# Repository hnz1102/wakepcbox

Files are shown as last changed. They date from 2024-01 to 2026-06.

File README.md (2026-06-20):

<div align="center">
  <h1><code>Wake PC Box</code></h1>
  <p>
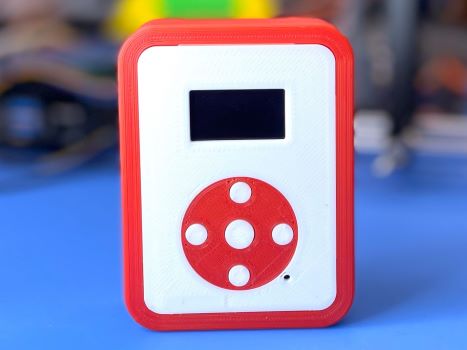
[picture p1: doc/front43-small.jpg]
    
  </p>
</div>

# Wake PC Box - Wake On LAN Packet Transmitting Box

Video
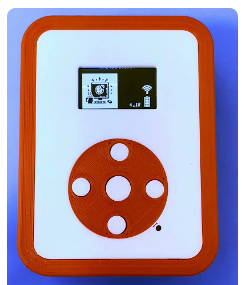
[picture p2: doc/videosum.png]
demo video (https://www.youtube.com/watch?v=YX_4e1eiLbk)


This is the small control box that can wake up the PC using Wake On LAN. You can just push a button, PCs will wake up from the power off status.
There is no need to start up another PC in order to start up a PC with Wake On Lan. Wake on LAN packets are sent via WiFi LAN.
The Box has a battery, and you can charge it from a USB Type-C port. Once charging full, you can use it for a month. If any buttons are not pressed for the specified time (default 30 seconds), the box will sleep automatically and conserve battery power. Up to four PCs can be registered.

# Update History
- 2024-05-30 : Initial Release
- 2026-02-14 : Update code for ESP-IDF V5.4.2 and update README.md
- 2026-06-20 : v0.2.0 - Add WPS PBC mode support, fix WPS display overlap, fix WiFi menu not reflecting WPS credentials immediately

# How it works

This box can send a Wake on LAN packet to the Wireless Access Point. To transfer the packet, the Access Point needs to be set to `Bridge Mode`. If `Router Mode` is set, the Access Point won't transfer to the wired LAN. 

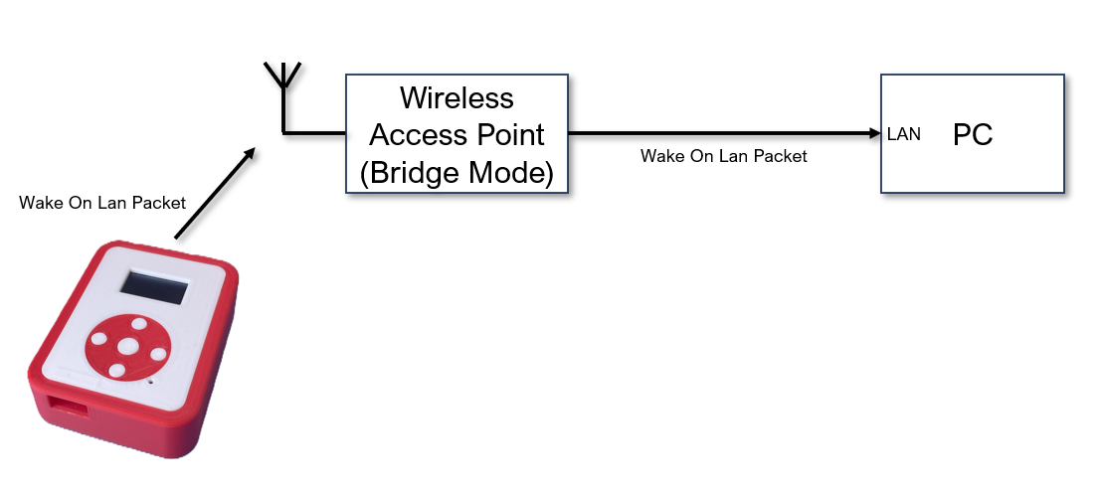
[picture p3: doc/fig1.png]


# Feature

**Quick Wake Up** -  Simply press one of the up, down, left, or right buttons to turn on the PC corresponding to that button. 4 PCs can be registered.

**Microcontroller on board** - No need for a PC when you turn on another PC. Directly send packets to the target PCs. 

**Transmit a packet via WiFi** - Wake-on LAN packets are transmitted via Wireless Network.

**Battery Powered** - Using LiPo battery. It can run for a month (In this case, every day a few times used).

**Small Handy Box** - This box is only 60mm(W) x 23mm(H) x 80mm(D) size. No need for any cables, it works. 

**Configurable** - Setting parameters are set from the display menu. SSID/Password/Target PC Hardware Address(4 PCs)/Time Zone/Sleep Time/Sleep Mode/Display Off Time/Reset Settings.

**WPS Support** - If `wps_enable = "true"` and `wifi_ssid` is empty in `cfg.toml`, the device enters WPS PBC (Push Button Configuration) mode on first boot. Press the WPS button on your router within 120 seconds. The obtained SSID and password are saved to NVS automatically, and subsequent boots connect normally without WPS.

# How to Use the Box
At first, you can set the WiFi SSID and PSK-Password in one of two ways:

**Option A: Manual entry via menu** - Push the Center Key to open the setting menu, select `WiFi`, then enter your SSID and password using the direction keys.

**Option B: WPS PBC mode** - Set `wps_enable = "true"` and leave `wifi_ssid` empty in `cfg.toml` before flashing. On first boot, the device displays "WPS MODE" and waits up to 120 seconds. Press the WPS button on your router to transfer the credentials automatically. The SSID and password are saved and WPS mode is disabled for subsequent boots.
Next, set the Hardware Address(Ethernet MAC Address) of the PC that you want to wake up. Select `HW Address` and push Center Key, select from `PC1` to `PC4`, push Center key, then enter your Hardware Address like `00:11:22:33:44:55`. 

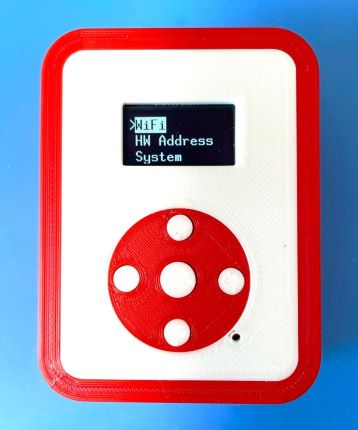
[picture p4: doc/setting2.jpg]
setting
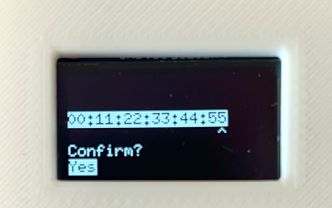
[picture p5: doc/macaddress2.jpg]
   

After setting, just push button corresponding the target.(Up Key : PC1, Down Key : PC2, Left Key: PC3, Right Key: PC4)

To charge a battery, just connect to a USB Type-C port from the bus-powered USB port. During the charge, the CHG LED is RED ON. After the charging is full, the FUL LED is GREEN ON. And the charging will be stopped automatically.

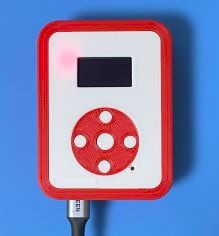
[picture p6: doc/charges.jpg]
charge
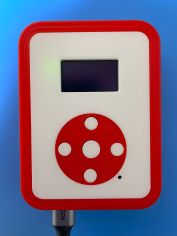
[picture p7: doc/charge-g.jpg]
charge
  

Assembled PCB

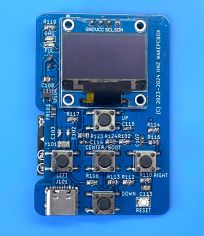
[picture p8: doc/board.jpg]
board
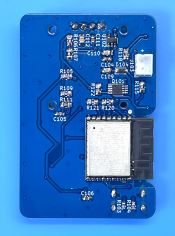
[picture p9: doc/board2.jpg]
board
    

Set in Box

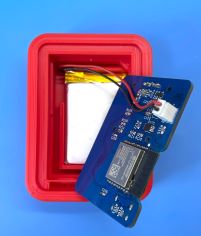
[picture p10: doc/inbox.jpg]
InBox
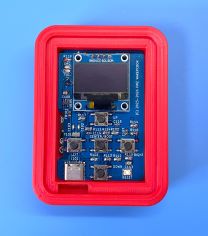
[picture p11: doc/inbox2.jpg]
InBox
   

# How to build from code and Install to the unit.

Using Ubuntu 22.04.3 LTS and ESP-IDF V5.4.2

1. Install Rust Compiler
```bash
sudo apt update && sudo apt -y install git python3 python3-pip gcc build-essential curl pkg-config libudev-dev libtinfo5 clang libclang-dev llvm-dev udev libssl-dev python3.10-venv
curl --proto '=https' --tlsv1.2 -sSf https://sh.rustup.rs | sh
```
You can see the install menu, select No.1. After installation, set the environment variable.

```bash
. "$HOME/.cargo/env"
```

2. Install toolchain for ESP32-C3
```bash
cargo install ldproxy
cargo install espup
cargo install cargo-espflash
```

3. Install ESP-IDF and set the environment variable.
```bash
espup install
espup update
```

Then, run the following command to set the environment for the ESP32-C3 toolchain:
```bash
. ./export-esp.sh
```

4. Add UDEV rules
```bash
sudo sh -c 'echo "SUBSYSTEMS==\"usb\", ATTRS{idVendor}==\"303a\", ATTRS{idProduct}==\"1001\", MODE=\"0666\"" > /etc/udev/rules.d/99-esp32.rules'
sudo udevadm control --reload-rules
sudo udevadm trigger
```

5. Download Current-Logger code
```bash
git clone https://github.com/hnz1102/wakepcbox.git
cd wakepcbox
``` 
6. Setting WiFi SSID, Password, and InfluxDB server IP address.
```bash
cfg.toml

[wakepcbox]
wifi_ssid = "<SSID>"      # Set your AP SSID. Leave empty to use WPS mode.
wifi_psk = "<Password>"   # Set password for SSID.
wps_enable = "false"       # Set "true" to use WPS PBC mode on first boot (requires wifi_ssid to be empty).
target_mac_address1 = "00:00:00:00:00:00"  # Set Hardware Address(MAC Address) for wakeup.
target_mac_address2 = "00:00:00:00:00:00"
target_mac_address3 = "00:00:00:00:00:00"
target_mac_address4 = "00:00:00:00:00:00"
timezone_offset = "0"
idle_in_sleep_time = "30"
sleep_mode = "light"
display_off_time = "30"
wakeup_interval = "10"
```
7. Build code and writing flash
```bashbash
cargo build --release
```

8. Connecting the board and Set device and set toolchain.

Connecting the Box by USB Type-C to this code building PC. Then, 

```bash
cargo espflash board-info

✔ Use serial port '/dev/ttyACM0' - USB JTAG/serial debug unit? · yes
✔ Remember this serial port for future use? · yes
[2026-02-14T04:41:35Z INFO ] Serial port: '/dev/ttyACM0'
[2026-02-14T04:41:35Z INFO ] Connecting...
[2026-02-14T04:41:36Z INFO ] Using flash stub
Chip type:         esp32c3 (revision v0.4)
Crystal frequency: 40 MHz
Flash size:        4MB
Features:          WiFi, BLE
MAC address:       a0:76:4e:b3:64:c0

Security Information:
=====================
Flags: 0x00000000 (0)
Key Purposes: [0, 0, 0, 0, 0, 0, 12]
Chip ID: 5
API Version: 3
Secure Boot: Disabled
Flash Encryption: Disabled
SPI Boot Crypt Count (SPI_BOOT_CRYPT_CNT): 0x0
```

9. Writing flash
```bash
cargo espflash flash --release --monitor

[2026-02-14T04:43:53Z INFO ] Serial port: '/dev/ttyACM0'
[2026-02-14T04:43:53Z INFO ] Connecting...
[2026-02-14T04:43:53Z INFO ] Using flash stub
   Compiling wakepcbox v0.1.0 (/wakepcbox)
    Finished `release` profile [optimized] target(s) in 4.22s
Chip type:         esp32c3 (revision v0.4)
Crystal frequency: 40 MHz
Flash size:        4MB
Features:          WiFi, BLE
MAC address:       a0:76:4e:b3:64:c0
App/part. size:    1,644,080/3,145,728 bytes, 52.26%
[00:00:00] [========================================]      13/13      0x0      Verifying... OK!                                                                                                                                                       [00:00:00] [========================================]       1/1       0x8000   Skipped! (checksum matches)                                                                                                                                            
[00:00:15] [========================================]     887/887     0x10000  Verifying... OK!                                                                                                                                                       [2026-02-14T04:44:16Z INFO ] Flashing has completed!

And automatically boot!
```
## Schematic, PCB Gabar and Container 3D Data

There is a Schematic data in the hardware directory including 3D printing data. 

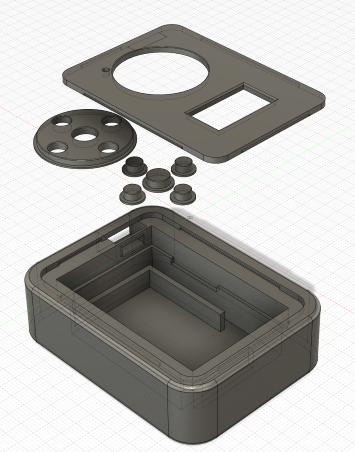
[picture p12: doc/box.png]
Container
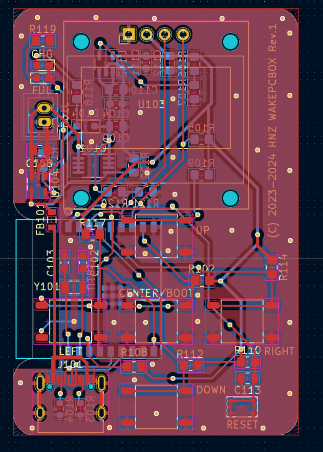
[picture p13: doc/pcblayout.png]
PCB Layout
 

## LICENSE
This source code is licensed under MIT. Other Hardware Schematic documents are licensed under CC-BY-SA V4.0.

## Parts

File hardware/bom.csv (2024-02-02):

Reference | Value | Footprint | Datasheet | digikey | distributor | Qty
C102, C103 | 16pF | Capacitor_SMD:C_0603_1608Metric_Pad1.08x0.95mm_HandSolder | ~ |  | https://www.digikey.com/en/products/detail/walsin-technology-corporation/0603N160J500CT/9354987 | 2
C104, C111 | 0.1uF | Capacitor_SMD:C_0603_1608Metric_Pad1.08x0.95mm_HandSolder | ~ |  | https://www.digikey.com/en/products/detail/yageo/CC0603ZRY5V9BB104/2103081 | 2
C108 | 4.7uF | Capacitor_SMD:C_0805_2012Metric_Pad1.18x1.45mm_HandSolder | ~ |  | https://www.digikey.com/en/products/detail/yageo/CC0805ZRY5V6BB475/2103109 | 1
C109, C113 | 1uF | Capacitor_SMD:C_0805_2012Metric | ~ |  | https://www.digikey.com/en/products/detail/yageo/CC0805ZRY5V7BB105/2833622 | 2
C110, C112 | 10uF | Capacitor_SMD:C_0805_2012Metric_Pad1.18x1.45mm_HandSolder | ~ |  | https://www.digikey.com/en/products/detail/murata-electronics/GRM21BR61C106KE15K/2546903 | 2
D102 | LED RED | LED_SMD:LED_0603_1608Metric_Pad1.05x0.95mm_HandSolder | ~ |  | https://www.digikey.com/en/products/detail/harvatek-corporation/B1931URO-20D000114U1930/15910603 | 1
D103 | LED GREEN | LED_SMD:LED_0603_1608Metric_Pad1.05x0.95mm_HandSolder | ~ |  | https://www.digikey.com/en/products/detail/harvatek-corporation/B1931NG-20D001114U1930/15861262 | 1
D104 | NSR0340HT1G | Diode_SMD:D_SOD-323_HandSoldering | https://www.onsemi.com/pub/Collateral/NSR0340H-D.PDF |  | https://www.digikey.com/en/products/detail/onsemi/NSR0340HT1G/1981491 | 1
FB101 | MH2029-601Y | Inductor_SMD:L_0805_2012Metric | ~ |  | https://www.digikey.com/en/products/detail/bourns-inc/MH2029-601Y/3741762 | 1
J101 | USB4105-GF-A | Library:USB_C_5077CR-16-SMC2-BK-TR | https://www.usb.org/sites/default/files/documents/usb_type-c.zip |  | https://www.digikey.com/en/products/detail/gct/USB4105-GF-A/11198441 | 1
J103 | LiPo BATTERY | Connector_JST:JST_PH_B2B-PH-K_1x02_P2.00mm_Vertical | ~ |  | https://www.digikey.com/en/products/detail/jst-sales-america-inc/B2B-PH-K-S/926611 | 1
Q101 | IRF7606TRPBF | Package_SO:MSOP-8_3x3mm_P0.65mm | http://www.irf.com/product-info/datasheets/data/irf7606pbf.pdf |  | https://www.digikey.com/en/products/detail/infineon-technologies/IRF7606TRPBF/856652 | 1
R102, R109, R110, R112, R114, R117 | 10K | Resistor_SMD:R_0805_2012Metric_Pad1.20x1.40mm_HandSolder | ~ |  | https://www.digikey.jp/en/products/detail/yageo/RC0603JR-1010KL/13694233 | 6
R103, R104 | 5.1K | Resistor_SMD:R_0603_1608Metric | ~ |  | https://www.digikey.com/en/products/detail/yageo/RC0603JR-075K1L/726796 | 2
R105, R108 | 10K | Resistor_SMD:R_0603_1608Metric | ~ |  | https://www.digikey.jp/en/products/detail/yageo/RC0603JR-1010KL/13694233 | 2
R106, R120, R121 | 20K 1% | Resistor_SMD:R_0805_2012Metric_Pad1.20x1.40mm_HandSolder | ~ |  | https://www.digikey.jp/en/products/detail/yageo/RC0603FR-0720KL/727040 | 3
R107 | 12K 1% | Resistor_SMD:R_0805_2012Metric_Pad1.20x1.40mm_HandSolder | ~ |  | https://www.digikey.com/en/products/detail/yageo/RC0603FR-0712KL/726913 | 1
R115 | 2K | Resistor_SMD:R_0805_2012Metric_Pad1.20x1.40mm_HandSolder | ~ |  | https://www.digikey.com/en/products/detail/yageo/RC0603JR-072KL/726726 | 1
R118, R119 | 330 | Resistor_SMD:R_0805_2012Metric_Pad1.20x1.40mm_HandSolder | ~ |  | https://www.digikey.com/en/products/detail/yageo/RC0603JR-13330RL/14286483 | 2
R122 | 100K | Resistor_SMD:R_0805_2012Metric_Pad1.20x1.40mm_HandSolder | ~ |  | https://www.digikey.com/en/products/detail/yageo/RC0603JR-07100KL/726698 | 1
SW101, SW103-SW106 | TS-06104 | Library:TS-06104 |  |  | https://akizukidenshi.com/catalog/g/g115969/ | 5
SW102 | 3.5x2.6 Tact SW | Library:WS-TASV SMT Tact Switch |  |  | https://www.digikey.com/en/products/detail/w%C3%BCrth-elektronik/435151014824/11627325 | 1
U101 | ESP32-C3-WROOM-02-N4 | Library:IC18_ESP32-C3-WROOM-02-N4_EXP | ESP32-C3-WROOM-02-N4 |  | https://www.digikey.com/en/products/detail/espressif-systems/ESP32-C3-WROOM-02-N4/14553031 | 1
U102 | SPX3819M5-L | Package_TO_SOT_SMD:SOT-23-5 | https://www.exar.com/content/document.ashx?id=22106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 |  | https://www.digikey.com/en/products/detail/maxlinear-inc/SPX3819M5-L-TR/2472388 | 1
U103 | SSD1306_DISPLAY | Library:OLED I2C DISPLAY |  |  | https://www.amazon.com/IZOKEE-Display-SSD1306-Raspberry-White-IIC/dp/B076PDVFQD/ref=sr_1_3 | 1
U104 | MCP73831-2-OT | Package_TO_SOT_SMD:SOT-23-5 | http://ww1.microchip.com/downloads/en/DeviceDoc/20001984g.pdf |  | https://www.digikey.com/en/products/detail/microchip-technology/MCP73831T-2ACI-OT/964301 | 1
Y101 | 32.7680KHz | Crystal:Crystal_SMD_3215-2Pin_3.2x1.5mm | ~ | 2151-RT3215-32.768-12.5-TRCT-ND | https://www.digikey.com/en/products/detail/raltron-electronics/RT3215-32-768-12-5-TR/10273025 | 1
BAT | LiPo Battery |  |  | https://www.amazon.com/EEMB-1100mAh-Battery-Rechargeable-Connector/dp/B08FD39Y5R | 1

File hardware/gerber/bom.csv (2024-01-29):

Designator | Footprint | Quantity | Value | LCSC Part #
C102, C103 | 0603 | 2 | 16pF
C104, C111 | 0603 | 2 | 0.1uF
C108 | 0805 | 1 | 4.7uF
C109, C113 | 0805 | 2 | 1uF
C110, C112 | 0805 | 2 | 10uF
D102 | 0603 | 1 | LED RED
D103 | 0603 | 1 | LED GREEN
D104 | D_SOD-323_HandSoldering | 1 | NSR0340HT1G
FB101 | 0805 | 1 | MH2029-601Y
J101 | USB_C_5077CR-16-SMC2-BK-TR | 1 | USB4105-GF-A
J103 | JST_PH_B2B-PH-K_1x02_P2.00mm_Vertical | 1 | LiPo BATTERY
Q101 | MSOP-8_3x3mm_P0.65mm | 1 | IRF7606TRPBF
R102, R109, R110, R112, R114, R117 | 0805 | 6 | 10K
R103, R104 | 0603 | 2 | 5.1K
R105, R108 | 0603 | 2 | 10K
R106, R120, R121 | 0805 | 3 | 20K 1%
R107 | 0805 | 1 | 12K 1%
R115 | 0805 | 1 | 2K
R118, R119 | 0805 | 2 | 330
R122 | 0805 | 1 | 100K
SW101, SW103, SW104, SW105, SW106 | TS-06104 | 5 | TS-06104
SW102 | WS-TASV SMT Tact Switch | 1 | 3.5x2.6 Tact SW
U101 | IC18_ESP32-C3-WROOM-02-N4_EXP | 1 | ESP32-C3-WROOM-02-N4
U102 | SOT-23-5 | 1 | SPX3819M5-L
U103 | OLED I2C DISPLAY | 1 | SSD1306_DISPLAY
U104 | SOT-23-5 | 1 | MCP73831-2-OT
Y101 | Crystal_SMD_3215-2Pin_3.2x1.5mm | 1 | 32.7680KHz

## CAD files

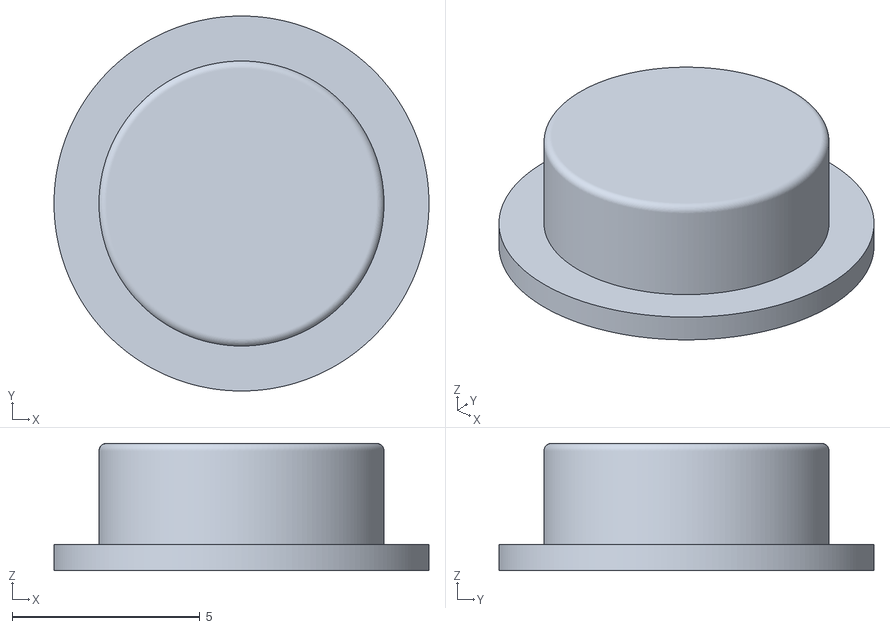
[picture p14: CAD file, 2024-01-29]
hardware/STL/button-center-v8.stl
10.0 x 10.0 x 3.40

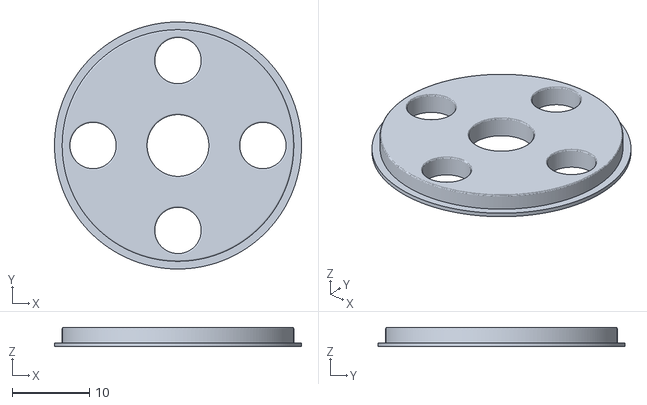
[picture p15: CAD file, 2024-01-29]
hardware/STL/button-gard-v11.stl
32.0 x 32.0 x 2.50

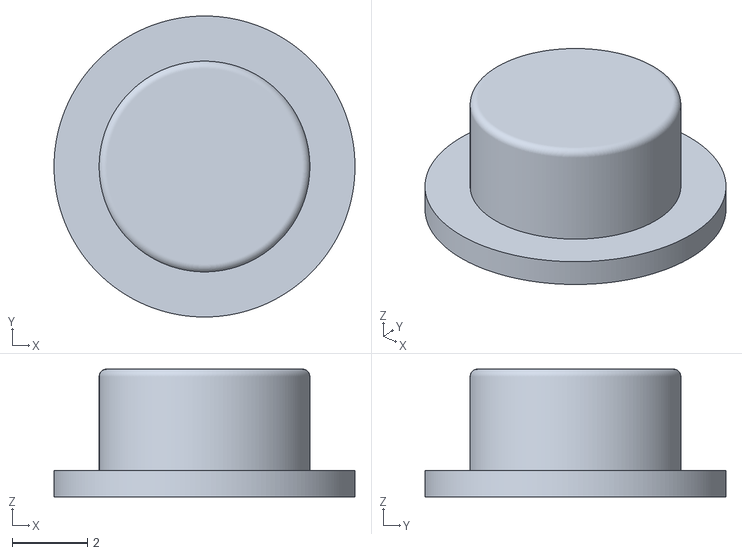
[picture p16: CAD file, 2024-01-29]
hardware/STL/button3-v8.stl
8.00 x 8.00 x 3.40

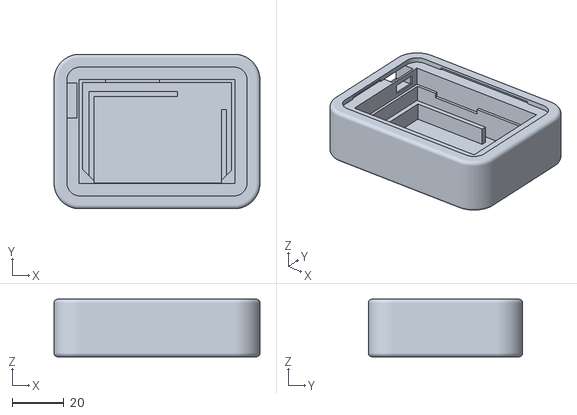
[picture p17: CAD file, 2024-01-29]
hardware/STL/bottom-v8.stl
80.0 x 60.0 x 22.4

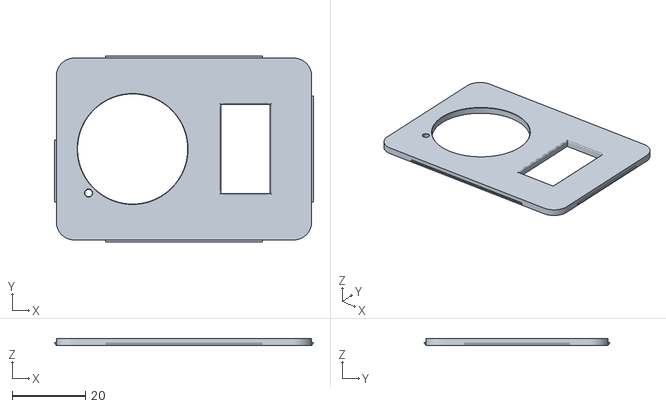
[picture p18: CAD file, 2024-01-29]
hardware/STL/upper-v8.stl
70.6 x 50.6 x 2.00

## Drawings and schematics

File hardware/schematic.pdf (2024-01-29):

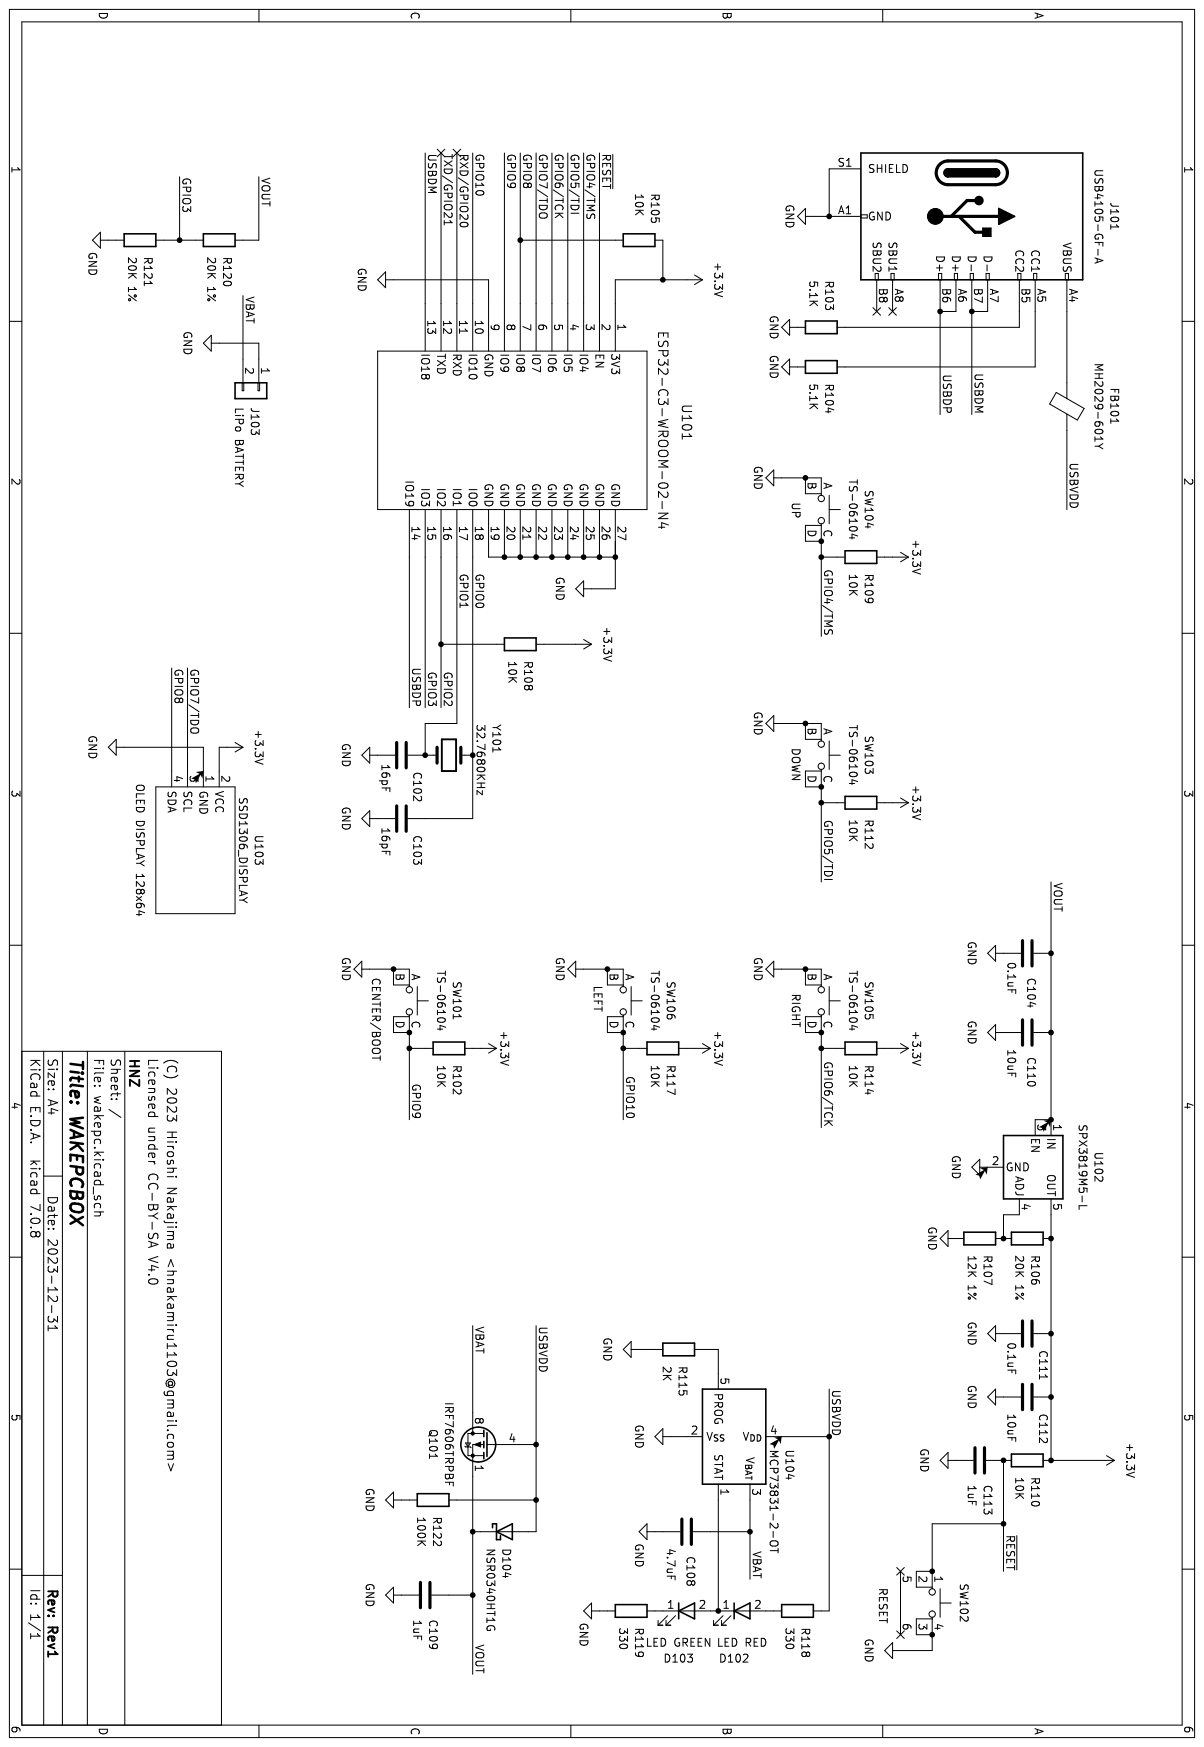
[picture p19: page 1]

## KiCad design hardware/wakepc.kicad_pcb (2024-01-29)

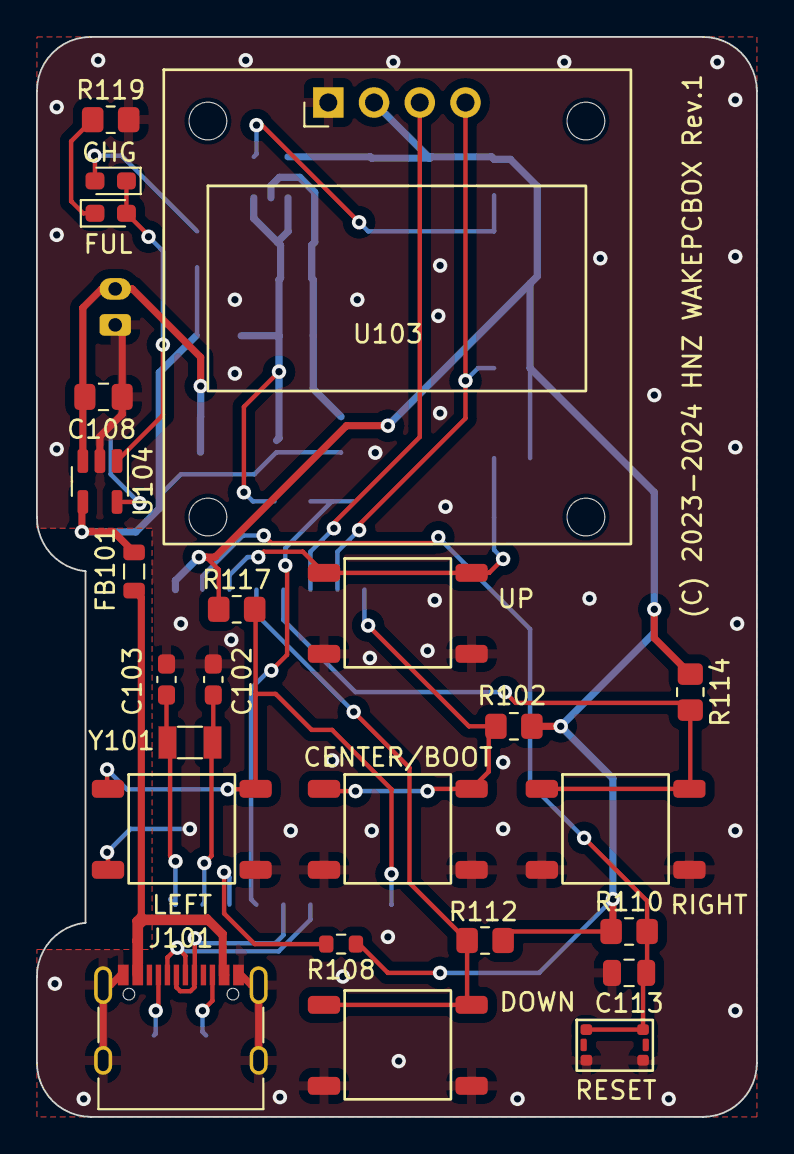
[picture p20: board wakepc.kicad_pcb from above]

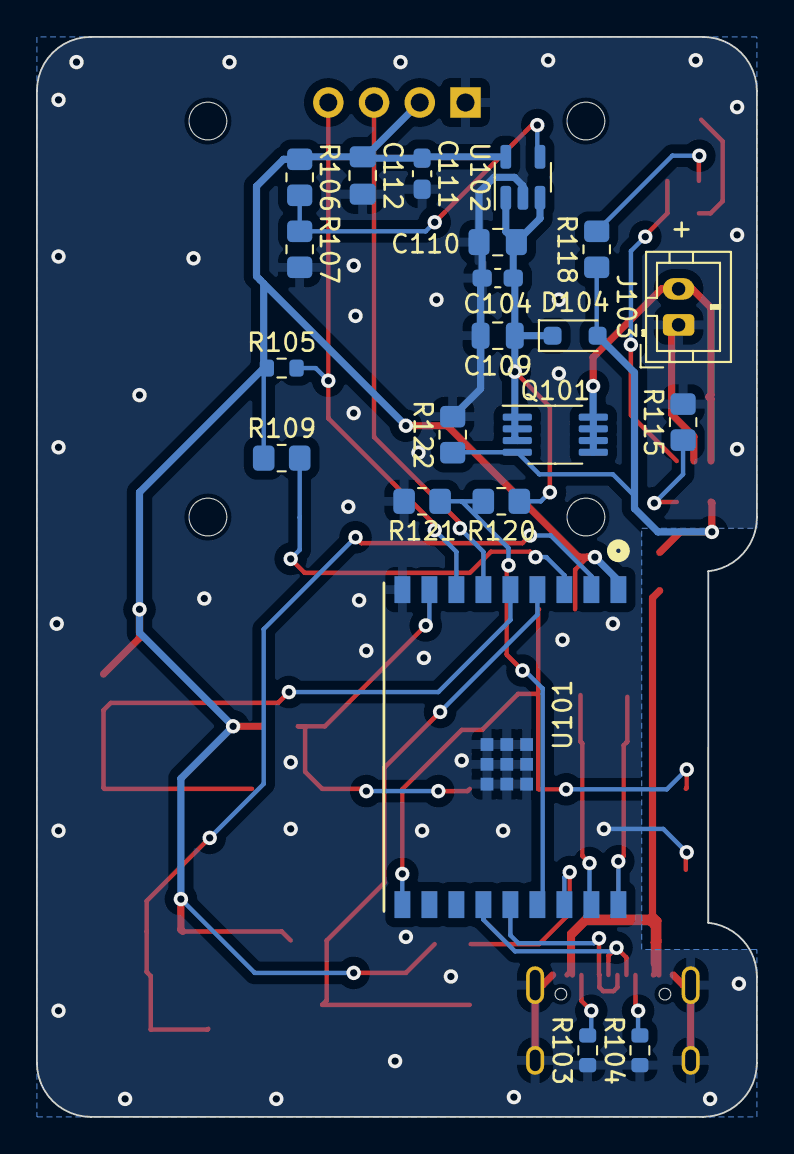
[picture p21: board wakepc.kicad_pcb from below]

Board: 2 copper layers, 40.0 x 60.0 mm, 45 parts (21 on the bottom side), 27 nets.

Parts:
C102, C103: 16pF; C_0603_1608Metric_Pad1.08x0.95mm_HandSolder
C104, C111: 0.1uF; C_0603_1608Metric_Pad1.08x0.95mm_HandSolder
C108: 4.7uF; C_0805_2012Metric_Pad1.18x1.45mm_HandSolder
C109, C113: 1uF; C_0805_2012Metric
C110, C112: 10uF; C_0805_2012Metric_Pad1.18x1.45mm_HandSolder
D102: LED RED; LED_0603_1608Metric_Pad1.05x0.95mm_HandSolder
D103: LED GREEN; LED_0603_1608Metric_Pad1.05x0.95mm_HandSolder
D104: NSR0340HT1G; D_SOD-323_HandSoldering
FB101: MH2029-601Y; L_0805_2012Metric
J101: USB4105-GF-A; USB_C_5077CR-16-SMC2-BK-TR
J103: LiPo BATTERY; JST_PH_B2B-PH-K_1x02_P2.00mm_Vertical
Q101: IRF7606TRPBF; MSOP-8_3x3mm_P0.65mm
R102, R109, R110, R112, R114, R117: 10K; R_0805_2012Metric_Pad1.20x1.40mm_HandSolder
R103, R104: 5.1K; R_0603_1608Metric
R105, R108: 10K; R_0603_1608Metric
R106, R120, R121: 20K 1%; R_0805_2012Metric_Pad1.20x1.40mm_HandSolder
R107: 12K 1%; R_0805_2012Metric_Pad1.20x1.40mm_HandSolder
R115: 2K; R_0805_2012Metric_Pad1.20x1.40mm_HandSolder
R118, R119: 330; R_0805_2012Metric_Pad1.20x1.40mm_HandSolder
R122: 100K; R_0805_2012Metric_Pad1.20x1.40mm_HandSolder
SW101, SW103, SW104, SW105, SW106: TS-06104
SW102: 3.5x2.6 Tact SW; WS-TASV SMT Tact Switch
U101: ESP32-C3-WROOM-02-N4; IC18_ESP32-C3-WROOM-02-N4_EXP
U102: SPX3819M5-L; SOT-23-5
U103: SSD1306_DISPLAY; OLED I2C DISPLAY
U104: MCP73831-2-OT; SOT-23-5
Y101: 32.7680KHz; Crystal_SMD_3215-2Pin_3.2x1.5mm

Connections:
+3.3V: C111.1, C112.1, R102.1, R105.1, R106.1, R108.1, R109.1, R110.1, R112.1, R114.1, R117.1, U101.1 (3V3), U102.5 (OUT), U103.2 (VCC)
/GPIO0: C103.1, U101.18 (IO0), Y101.2
/GPIO1: C102.1, U101.17 (IO1), Y101.1
/GPIO2: R108.2, U101.16 (IO2)
/GPIO3: R120.2, R121.1, U101.15 (IO3)
/GPIO4/TMS: R109.2, SW104.C, SW104.D, U101.3 (IO4)
/GPIO5/TDI: R112.2, SW103.C, SW103.D, U101.4 (IO5)
/GPIO6/TCK: R114.2, SW105.C, SW105.D, U101.5 (IO6)
/GPIO7/TDO: U101.6 (IO7), U103.3 (SCL)
/GPIO8: R105.2, U101.7 (IO8), U103.4 (SDA)
/GPIO9: R102.2, SW101.C, SW101.D, U101.8 (IO9)
/GPIO10: R117.2, SW106.C, SW106.D, U101.10 (IO10)
/USBDM: J101.A7 (D-), J101.B7 (D-), U101.13 (IO18)
/USBDP: J101.A6 (D+), J101.B6 (D+), U101.14 (IO19)
/USBVDD: D104.2 (A), FB101.2, Q101.4 (G), R118.1, R122.1, U104.4 (V_{DD})
/VBAT: C108.1, J103.2, Q101.5 (D), Q101.6 (D), Q101.7 (D), Q101.8 (D), U104.3 (V_{BAT})
/VOUT: C104.1, C109.1, C110.1, D104.1 (K), Q101.1 (S), Q101.2 (S), Q101.3 (S), R120.1, U102.1 (IN), U102.3 (EN)
/~RESET: C113.1, R110.2, SW102.1, SW102.2, U101.2 (EN)
GND: C102.2, C103.2, C104.2, C108.2, C109.2, C110.2, C111.2, C112.2, C113.2, J101.A1 (GND), J101.A12 (GND), J101.B1 (GND), J101.B12 (GND), J101.S1 (SHIELD), J103.1, R103.1, R104.1, R107.2, R115.2, R119.2, R121.2, R122.2, SW101.A, SW101.B, SW102.3 (K), SW102.4 (A), SW103.A, SW103.B, SW104.A, SW104.B, SW105.A, SW105.B, SW106.A, SW106.B, U101.9 (GND), U101.19 (GND), U101.20 (GND), U101.21 (GND), U101.22 (GND), U101.23 (GND), U101.24 (GND), U101.25 (GND), U101.26 (GND), U101.27 (GND), U102.2 (GND), U103.1 (GND), U104.2 (V_{SS})
unnamed: D102.2 (A), R118.2
unnamed: D102.1 (K), D103.2 (A), U104.1 (STAT)
unnamed: D103.1 (K), R119.1
unnamed: FB101.1, J101.A4 (VBUS), J101.A9 (VBUS), J101.B4 (VBUS), J101.B9 (VBUS)
unnamed: J101.A5 (CC1), R104.2
unnamed: J101.B5 (CC2), R103.2
unnamed: R106.2, R107.1, U102.4 (ADJ)
unnamed: R115.1, U104.5 (PROG)

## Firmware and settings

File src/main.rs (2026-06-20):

use std::{thread, time::Duration};
use esp_idf_hal::{gpio::*, prelude::*, i2c};
use esp_idf_hal::peripherals::Peripherals;
use esp_idf_svc::nvs::{EspNvs, EspNvsPartition, NvsDefault, NvsPartitionId};
use esp_idf_svc::sntp::{EspSntp, SyncStatus, SntpConf, OperatingMode, SyncMode};
use esp_idf_hal::adc::oneshot::config::AdcChannelConfig;
use esp_idf_hal::adc::oneshot::config::Calibration;
use esp_idf_hal::adc::oneshot::*;
use esp_idf_hal::adc::attenuation::DB_11;
use esp_idf_svc::wifi::EspWifi;
use log::*;

use std::net::Ipv4Addr;
use std::time::{SystemTime, UNIX_EPOCH};

mod wifi;
mod displayctl;
mod keyevent;
mod wakepacket;
mod ui;
mod config;

use displayctl::{DisplayPanel, WiFiStatus, MessageTypes};
use keyevent::{KeySwitch, KeyEvent};
use config::ConfigData;

const SLEEP_MODE_LIGHT : &'static str = "light";
#[allow(dead_code)]
const SLEEP_MODE_DEEP : &'static str = "deep";

const GPIO_WAKEUP_INT_PIN_4 : i32 = 4;
const GPIO_WAKEUP_INT_PIN_5 : i32 = 5;
const GPIO_WAKEUP_INT_PIN_6 : i32 = 6;
const GPIO_WAKEUP_INT_PIN_9 : i32 = 9;
const GPIO_WAKEUP_INT_PIN_10 : i32 = 10;

const GPIO_WAKEUP_INT_PIN : u64 = 16 + 32;
const MAX_NVS_STR_SIZE : usize = 3072;

fn main() -> anyhow::Result<()> {
    esp_idf_sys::link_patches();
    esp_idf_svc::log::EspLogger::initialize_default();

    // Peripherals Initialize
    let peripherals = Peripherals::take().unwrap();
    // Gpio Initialize
    let up_key = peripherals.pins.gpio4;
    let down_key = peripherals.pins.gpio5;
    let left_key = peripherals.pins.gpio10;
    let right_key = peripherals.pins.gpio6;
    let enter_key = peripherals.pins.gpio9;

    let upkey_sig = Box::new(PinDriver::input(up_key)?);
    let downkey_sig = Box::new(PinDriver::input(down_key)?);
    let leftkey_sig = Box::new(PinDriver::input(left_key)?);
    let rightkey_sig = Box::new(PinDriver::input(right_key)?);
    let enterkey_sig = Box::new(PinDriver::input(enter_key)?);

    // Display Initialize
    let i2c = peripherals.i2c0;
    let scl = peripherals.pins.gpio7;
    let sda = peripherals.pins.gpio8;
    let config_i2c = i2c::I2cConfig::new().baudrate(1.MHz().into());
    let i2c = i2c::I2cDriver::new(i2c, sda, scl, &config_i2c)?;
    let mut dp = DisplayPanel::new();
    dp.start(i2c);
    dp.set_display_active(true);
    dp.set_initial_logo(true);

    // Initialize ADC
    let mut adc = AdcDriver::new(peripherals.adc1)?;
    let mut adc_config = AdcChannelConfig {
        attenuation: DB_11,
        calibration: Calibration::Curve, // Use curve calibration for better accuracy
        ..Default::default()
    };
    let mut adc_pin = AdcChannelDriver::new(&mut adc, peripherals.pins.gpio3, &mut adc_config)?;
    
    // Initialize nvs
    let wakeup_reason : u32;
    unsafe {
        wakeup_reason = esp_idf_sys::esp_sleep_get_wakeup_cause();
        if wakeup_reason == esp_idf_sys::esp_sleep_source_t_ESP_SLEEP_WAKEUP_UNDEFINED {
            info!("First boot");
            if upkey_sig.is_low() {
                info!("Erase NVS flash...");
                dp.set_main_msg(&"Erase NVS flash...".to_string(), MessageTypes::Status);
                esp_idf_sys::nvs_flash_erase();
                thread::sleep(Duration::from_millis(1000));
            }    
            esp_idf_sys::nvs_flash_init();
        } else {
            info!("Wakeup reason: {:?}", wakeup_reason);
        }
    }


    let mut keysw = KeySwitch::new();
    keysw.start(upkey_sig, downkey_sig, rightkey_sig, enterkey_sig, leftkey_sig);

    // Initialize Configuration Data
    let mut config_data = ConfigData::new();

    // Initialize NVS
    let nvs_default_partition = EspNvsPartition::<NvsDefault>::take().unwrap();
    let mut nvs = match EspNvs::new(nvs_default_partition, "storage", true) {
        Ok(nvs) => { info!("NVS storage area initialized"); nvs },
        Err(ref e) => {
            dp.set_main_msg(&"NVS initialization failed.".to_string(), MessageTypes::Error); 
            panic!("NVS initialization failed {:?}", e); }
    };

    // Load config
    let mut nvs_buf : [u8 ; MAX_NVS_STR_SIZE] = [0; MAX_NVS_STR_SIZE];
    let nvs_value = match nvs.get_str("config", &mut nvs_buf){
        Ok(value) => { info!("Try to read NVS config"); value },
        Err(ref e) => { info!("NVS config not found {:?}", e); None }
    };
    if nvs_value == None {
        info!("NVS config not found. Set default config");
        set_default_config(&mut config_data, &mut nvs);
        dp.set_main_msg(&"Using default settings.".to_string(), MessageTypes::Status);
        thread::sleep(Duration::from_millis(1000));
    }
    else {
        info!("NVS config found {:?}", nvs_value);
        match config_data.load_config(nvs_value) {
            Ok(_) => { info!("Config load success"); },
            Err(ref e) => { 
                info!("Config load failed {:?}", e);
                dp.set_main_msg(&"Using default settings.".to_string(), MessageTypes::Status);
                set_default_config(&mut config_data, &mut nvs);
                thread::sleep(Duration::from_millis(1000));
            },
        }    
    }

    dp.initialize_menu(&config_data);
    info!("SSID: {}", config_data.wifi_ssid);

    // Initialize Wakepacket
    let mut wp = wakepacket::WakePacket::new();
    wp.set_target_mac(wakepacket::TargetDevice::Device1, &config_data.target_mac_address1);
    wp.set_target_mac(wakepacket::TargetDevice::Device2, &config_data.target_mac_address2);
    wp.set_target_mac(wakepacket::TargetDevice::Device3, &config_data.target_mac_address3);
    wp.set_target_mac(wakepacket::TargetDevice::Device4, &config_data.target_mac_address4);
    // Set Timezone
    dp.set_timezone_offset(config_data.timezone_offset);
    dp.set_initial_logo(false);

    // Initialize WiFi
    dp.set_wifi_status(WiFiStatus::Connecting);
    let mut wifi_dev: Result<Box<EspWifi<'static>>, anyhow::Error>;
    if config_data.wps_enable && config_data.wifi_ssid.is_empty() {
        // WPS PBC mode: no SSID configured, use WPS to obtain credentials
        dp.set_main_msg(&"WPS Mode".to_string(), MessageTypes::Status);
        dp.set_second_msg(&"Press WPS button".to_string());
        let wps_result = wifi::wifi_connect_wps(
            peripherals.modem,
            |title, msg| {
                dp.set_main_msg(&msg.to_string(), MessageTypes::Status);
                dp.set_second_msg(&title.to_string());
            },
        );
        match wps_result {
            Ok((wps_wifi, wps_ssid, wps_psk)) => {
                info!("[WPS] Connected: SSID={}", wps_ssid);
                // Save WPS credentials to NVS for next boot
                config_data.wifi_ssid = wps_ssid;
                config_data.wifi_psk = wps_psk;
                config_data.wps_enable = false; // next boot: connect normally with saved credentials
                let toml_string = convert_config_to_toml_string(&config_data.to_config_entries());
                match nvs.set_str("config", &toml_string) {
                    Ok(_) => { info!("[WPS] Credentials saved to NVS"); },
                    Err(ref e) => { info!("[WPS] Failed to save credentials: {:?}", e); },
                }
                // Re-initialize menu so that the WPS-obtained SSID/PSK are reflected
                // (initialize_menu was called before WPS with empty credentials)
                dp.initialize_menu(&config_data);
                dp.set_wifi_status(WiFiStatus::Connected);
                wifi_dev = Ok(wps_wifi);
            },
            Err(ref e) => {
                info!("[WPS] Failed: {:?}", e);
                dp.set_main_msg(&"WPS Failed".to_string(), MessageTypes::Error);
                wifi_dev = Err(anyhow::anyhow!("WPS failed: {}", e));
            },
        }
    } else {
        // Normal SSID+PSK connection
        dp.set_main_msg(&"Connecting WiFi..".to_string(), MessageTypes::Status);
        dp.set_second_msg(&format!("AP:{}", config_data.wifi_ssid));
        wifi_dev = wifi::wifi_connect(peripherals.modem, &config_data.wifi_ssid, &config_data.wifi_psk);
        match &wifi_dev {
            Ok(_) => { dp.set_wifi_status(WiFiStatus::Connected); },
            Err(ref e) => { info!("{:?}", e); }
        }
    }
      
    // Get my IP address
    let mut ip_addr : Ipv4Addr; 
    let mut retry_count : u32 = 0;
    loop {
        ip_addr = wifi_dev.as_ref().unwrap().sta_netif().get_ip_info().unwrap().ip;
        if ip_addr != Ipv4Addr::new(0, 0, 0, 0) {
            break;
        }
        info!("Waiting for WiFi connection...");
        thread::sleep(Duration::from_secs(1));
        retry_count += 1;
        if retry_count > 30 {
            info!("WiFi connection timeout");
            break;
        }
    }

    // NTP Server
    let sntp_conf = SntpConf {
        servers: ["time.aws.com",
                  "time.google.com",
                  "time.cloudflare.com",
                  "ntp.nict.jp"],
        operating_mode: OperatingMode::Poll,
        sync_mode: SyncMode::Immediate,
    };
    let ntp = EspSntp::new(&sntp_conf).unwrap();

    info!("IP address: {}", ip_addr);
    dp.set_second_msg(&format!("IP: {}", ip_addr));

    // NTP Sync
    let now = SystemTime::now();
    if now.duration_since(UNIX_EPOCH).unwrap().as_millis() < 1700000000 {
        info!("NTP Sync Start..");
        dp.set_main_msg(&"NTP Syncing..".to_string(), MessageTypes::Status);
        // No wait for sync
        // while ntp.get_sync_status() != SyncStatus::Completed {
        //     thread::sleep(Duration::from_millis(10));
        // }
        // let now = SystemTime::now();
        // let dt_now : DateTime<Utc> = now.into();
        // let formatted = format!("{}", dt_now.format("%Y-%m-%d %H:%M:%S"));
        // info!("NTP Sync Completed: {}", formatted);
    } 

    // Main Loop
    let mut send_count : u32 = 0;
    let mut loop_count : u32 = 0;
    let mut start_time = SystemTime::now();
    let mut rssi : i32;
    loop {
        // Get Battery Voltage
        let battery_voltage : f32 =  adc_pin.read().unwrap() as f32 * 2.0 / 1000.0;
        dp.set_battery_voltage(battery_voltage);
        // Get RSSI
        rssi = wifi::get_rssi();
        dp.set_wifi_rssi(rssi);
        if rssi == 0 {
            wifi_reconnect(&mut wifi_dev.as_mut().unwrap(), &mut dp);
        }
        else {
            dp.set_wifi_status(WiFiStatus::Connected);
        }

        // If need to sync time
        match start_time.elapsed() {
            Ok(elapsed) => {
                if elapsed.as_secs() > 3600 {
                    info!("NTP Sync Start..");
                    dp.set_main_msg(&"NTP Syncing..".to_string(), MessageTypes::Status);
                    let sync_status = ntp.get_sync_status();
                    if sync_status != SyncStatus::Completed {
                        start_time = SystemTime::now();
                    } 
                }
            },
            Err(e) => {
                info!("Error: {:?}", e);
            }
        }
        // Get Key Event
        let mut target_device : wakepacket::TargetDevice = wakepacket::TargetDevice::None;
        dp.set_main_msg(&"Push Button..".to_string(), MessageTypes::Ready);
        let key_envet = keysw.get_key_event_and_clear();
        for it in key_envet {
            info!("Key Event: {:?}", it);
            match it {
                KeyEvent::UpKeyUp | KeyEvent::UpKeyDown => {
                    target_device = wakepacket::TargetDevice::Device1;
                    info!("Up key pressed. Target device1");
                    dp.set_main_msg(&"PC1".to_string(), MessageTypes::Progress);
                    break;
                },
                KeyEvent::DownKeyUp | KeyEvent::DownKeyDown => {
                    target_device = wakepacket::TargetDevice::Device2;
                    info!("Down key pressed. Target device2");
                    dp.set_main_msg(&"PC2".to_string(), MessageTypes::Progress);
                    break;
                },
                KeyEvent::LeftKeyUp | KeyEvent::LeftKeyDown => {
                    target_device = wakepacket::TargetDevice::Device3;
                    info!("Left key pressed. Target device3");
                    dp.set_main_msg(&"PC3".to_string(), MessageTypes::Progress);
                    break;
                },
                KeyEvent::RightKeyUp | KeyEvent::RightKeyDown => {
                    target_device = wakepacket::TargetDevice::Device4;
                    info!("Right key pressed. Target device4");
                    dp.set_main_msg(&"PC4".to_string(), MessageTypes::Progress);
                    break;
                },
                KeyEvent::CenterKeyUp | KeyEvent::CenterKeyDown => {
                    info!("Enter key pressed. Show menu");
                    dp.set_display_active(true);
                    let config = select_menu(&mut dp, &mut keysw);
                    if config != None {
                        if is_going_to_reset(config.as_ref().unwrap()) {
                            info!("Reset config");
                            unsafe {
                                esp_idf_sys::nvs_flash_erase();
                            }
                            dp.set_main_msg(&"Reset Config...".to_string(), MessageTypes::Status);
                            thread::sleep(Duration::from_secs(3));
                        }
                        else {
                            let toml_string = convert_config_to_toml_string(&config.unwrap());
                            info!("New config: {}", toml_string);
                            let _ = nvs.set_str("config", &toml_string);
                        }
                        dp.set_main_msg(&"Restarting...".to_string(), MessageTypes::Status);
                        thread::sleep(Duration::from_secs(1));
                        unsafe {
                            esp_idf_sys::esp_restart();
                        }
                    }
                    else {
                        dp.set_main_msg(&"No Save...".to_string(), MessageTypes::Status);
                    }
                    thread::sleep(Duration::from_secs(1));
                    keysw.clear_all_button_event();
                    loop_count = 0;
                    break;
                }
            }
        }
        if target_device != wakepacket::TargetDevice::None {
            dp.set_display_active(true);
            let mut send_retry_count : u32 = 0;
            loop {
                thread::sleep(Duration::from_secs(1));
                let status = wp.send_pkt(target_device);
                if !status.is_err() {
                    send_count += 1;
                    dp.set_send_pkt(send_count);
                    dp.set_main_msg(&"Completed.".to_string(), MessageTypes::WakeUp);
                    thread::sleep(Duration::from_secs(2));
                    keysw.clear_all_button_event();
                    break;
                }
                else {
                    send_retry_count += 1;
                    info!("Send magic packet failed");
                    if send_retry_count >= 5 {
                        dp.set_main_msg(&"Send Failed.".to_string(), MessageTypes::Error);
                        break;
                    }
                }
            }
            loop_count = 0;
        }
        else {
            loop_count += 1;
        }
        if config_data.idle_in_sleep_time == 0 {
            if config_data.display_off_time > 0 && loop_count >= config_data.display_off_time {
                loop_count = 0;
                // display off
                dp.set_display_active(false);
            }
        }
        else {
            // Sleep
            if loop_count >= config_data.idle_in_sleep_time {
                info!("Sleep Now...");
                dp.set_main_msg(&"Sleeping..".to_string(), MessageTypes::Status);
                dp.set_wifi_status(WiFiStatus::Disconnected);
                thread::sleep(Duration::from_millis(1000));
                dp.set_display_active(false);
                unsafe {
                    esp_idf_sys::esp_wifi_stop();
                }
                thread::sleep(Duration::from_millis(1000));
                loop_count = 0;
                unsafe {
                    // light sleep mode
                    if config_data.sleep_mode == SLEEP_MODE_LIGHT {
                        // gpio wakeup enable
                        esp_idf_sys::gpio_wakeup_enable(GPIO_WAKEUP_INT_PIN_4, esp_idf_sys::gpio_int_type_t_GPIO_INTR_LOW_LEVEL);
                        esp_idf_sys::gpio_wakeup_enable(GPIO_WAKEUP_INT_PIN_5, esp_idf_sys::gpio_int_type_t_GPIO_INTR_LOW_LEVEL);
                        esp_idf_sys::gpio_wakeup_enable(GPIO_WAKEUP_INT_PIN_6, esp_idf_sys::gpio_int_type_t_GPIO_INTR_LOW_LEVEL);
                        esp_idf_sys::gpio_wakeup_enable(GPIO_WAKEUP_INT_PIN_9, esp_idf_sys::gpio_int_type_t_GPIO_INTR_LOW_LEVEL);
                        esp_idf_sys::gpio_wakeup_enable(GPIO_WAKEUP_INT_PIN_10, esp_idf_sys::gpio_int_type_t_GPIO_INTR_LOW_LEVEL);
                        esp_idf_sys::esp_sleep_enable_gpio_wakeup();
                        // wakeup from rtc timer
                        // esp_idf_sys::esp_sleep_enable_timer_wakeup(config_data.wakeup_interval as u64 * 1000);
                    }
                    else {
                        info!("Deep Sleep Start");
                        esp_idf_sys::esp_deep_sleep_enable_gpio_wakeup(GPIO_WAKEUP_INT_PIN, esp_idf_sys::esp_deepsleep_gpio_wake_up_mode_t_ESP_GPIO_WAKEUP_GPIO_LOW);
                        esp_idf_sys::esp_deep_sleep_start();
                    }

                    // deep sleep mode (not here)
                    if config_data.sleep_mode == SLEEP_MODE_LIGHT {
                        let _result = esp_idf_sys::esp_light_sleep_start();
                        // gpio interrupt enable
                        esp_idf_sys::gpio_set_intr_type(GPIO_WAKEUP_INT_PIN_4, esp_idf_sys::gpio_int_type_t_GPIO_INTR_ANYEDGE);
                        esp_idf_sys::gpio_set_intr_type(GPIO_WAKEUP_INT_PIN_5, esp_idf_sys::gpio_int_type_t_GPIO_INTR_ANYEDGE);
                        esp_idf_sys::gpio_set_intr_type(GPIO_WAKEUP_INT_PIN_6, esp_idf_sys::gpio_int_type_t_GPIO_INTR_ANYEDGE);
                        esp_idf_sys::gpio_set_intr_type(GPIO_WAKEUP_INT_PIN_9, esp_idf_sys::gpio_int_type_t_GPIO_INTR_ANYEDGE);
                        esp_idf_sys::gpio_set_intr_type(GPIO_WAKEUP_INT_PIN_10, esp_idf_sys::gpio_int_type_t_GPIO_INTR_ANYEDGE);
                        continue;
                    }
                }
            }
        }
        thread::sleep(Duration::from_secs(1));
    }
}

fn wifi_reconnect(wifi_dev: &mut EspWifi, dp: &mut DisplayPanel) -> bool{
    // display on
    dp.set_wifi_status(WiFiStatus::Connecting);
    unsafe {
        esp_idf_sys::esp_wifi_start();
    }
    match wifi_dev.connect() {
        Ok(_) => { info!("Wifi connected"); true},
        Err(ref e) => { info!("{:?}", e); false }
    }
}



fn select_menu(dp: &mut DisplayPanel, keysw: &mut KeySwitch) -> Option<Vec<(String, String)>> {
    dp.reset_menu();
    dp.set_main_msg(&"Menu".to_string(), MessageTypes::Menu);
    thread::sleep(Duration::from_millis(300));
    keysw.clear_all_button_event();
    loop {
        let key_envet = keysw.get_key_event_and_clear();
        for it in key_envet {
            info!("Key Event: {:?}", it);
            let (exit, data) = dp.key_event_input(it);
            if exit {
                return data;
            }
        }
        thread::sleep(Duration::from_millis(10));
    }
}

fn is_going_to_reset(keyval: &Vec<(String, String)>) -> bool {
    for it in keyval {
        if it.0 == "RESETCONFIG" {
            return true;
        }
    }
    false
}

fn set_default_config<T : NvsPartitionId>(config: &mut ConfigData, nvs: &mut EspNvs<T>){
    let default_config = config.set_default_config();
    let toml_cfg = convert_config_to_toml_string(&default_config);
    match nvs.set_str("config", toml_cfg.as_str()) {
        Ok(_) => { info!("Set default config"); },
        Err(ref e) => { info!("Set default config failed {:?}", e); }
    }
    config.load_config(Some(toml_cfg.as_str())).unwrap();
}

fn convert_config_to_toml_string(keyval: &Vec<(String, String)>) -> String {
    let mut toml_string = String::new();
    for it in keyval {
        toml_string.push_str(&format!("{} = \"{}\"\n", it.0, it.1));
    }
    toml_string
}

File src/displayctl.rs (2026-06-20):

use log::*;
use std::{thread, time::Duration, sync::Arc, sync::Mutex};
use esp_idf_hal::i2c;
use ssd1306::{I2CDisplayInterface, prelude::*, Ssd1306};
use embedded_graphics::{
    mono_font::{ascii::{FONT_10X20, FONT_5X8, FONT_6X10}, MonoTextStyle, MonoTextStyleBuilder},
    image::{Image},
    pixelcolor::BinaryColor,
    text::{Text},
    geometry::Point,
    prelude::*,
};
use tinybmp::Bmp;
use chrono::{DateTime, Utc, Local, FixedOffset};
use std::time::{SystemTime, UNIX_EPOCH};

use crate::ui::{MenuTable, MenuType, InputTypeChar};
use crate::keyevent::{KeyEvent};
use crate::ConfigData;

const MAIN_MENU_WIFI : usize = 0;
const MAIN_MENU_HWADDR : usize = 1;
const MAIN_MENU_SYSTEM : usize = 2;

pub enum WiFiStatus {
    Disconnected,
    Connecting,
    Connected,
}

#[derive(PartialEq)]
pub enum MessageTypes {
    None,
    Ready,
    Progress,
    WakeUp,
    Status,
    Error,
    Menu,
}

type DISPLAYIF<'d> = i2c::I2cDriver<'static>;

struct DisplayText {
    display_active: bool,
    main_msg: String,
    second_msg: String,
    msg_type: MessageTypes, 
    wifi_status: WiFiStatus,
    wifi_rssi: i32,
    num_send_pkt: u32,
    initial_logo: bool,
    timezone_offset: i32,
    battery_voltage: f32,
    menu_table: MenuTable,
}

pub struct DisplayPanel {
    txt: Arc<Mutex<DisplayText>>
}

impl DisplayPanel {
    pub fn new() -> DisplayPanel {
        DisplayPanel { txt: Arc::new(Mutex::new(
            DisplayText {   display_active: false,
                            second_msg: "".to_string(),
                            main_msg: "".to_string(),
                            msg_type: MessageTypes::None,
                            wifi_status: WiFiStatus::Disconnected,
                            wifi_rssi: 0,
                            num_send_pkt: 0,
                            initial_logo: false,
                            timezone_offset: 0,
                            battery_voltage: 0.0,
                            menu_table: MenuTable::new(),
                     })) }
    }

    pub fn start(&mut self, i2c : DISPLAYIF )
    {
        let txt = self.txt.clone();
        let _th = thread::spawn(move || {
            info!("Start Display Thread.");
            let interface = I2CDisplayInterface::new(i2c);        
            let mut display = Ssd1306::new(interface, 
                DisplaySize128x64,
                ssd1306::prelude::DisplayRotation::Rotate0)
                .into_buffered_graphics_mode();        
            display.init().unwrap();
            let style_large = MonoTextStyle::new(&FONT_10X20, BinaryColor::On);
            let style_large_inv = MonoTextStyleBuilder::new()
                .font(&FONT_10X20)
                .text_color(BinaryColor::Off)
                .background_color(BinaryColor::On)
                .build();
            let style_small = MonoTextStyle::new(&FONT_5X8, BinaryColor::On);
            let style_middle = MonoTextStyle::new(&FONT_6X10, BinaryColor::On);
            let style_middle_inv = MonoTextStyleBuilder::new()
                .font(&FONT_6X10)
                .text_color(BinaryColor::Off)
                .background_color(BinaryColor::On)
                .build();
            
            // Clear display
            display.clear(BinaryColor::Off).unwrap();
            display.flush().unwrap();
            // Logo BMP
            let logobmp = Bmp::from_slice(include_bytes!("./img/wakepcbox.bmp")).unwrap();
            let logo_img: Image<Bmp<BinaryColor>> = Image::new(&logobmp, Point::new(0,0));

            // Wifi BMP
            let wifibmp0 = Bmp::from_slice(include_bytes!("./img/wifi-0.bmp")).unwrap();
            let wifi_img0: Image<Bmp<BinaryColor>> = Image::new(&wifibmp0, Point::new(108,20));
            let wifibmp1 = Bmp::from_slice(include_bytes!("./img/wifi-1.bmp")).unwrap();
            let wifi_img1: Image<Bmp<BinaryColor>> = Image::new(&wifibmp1, Point::new(108,20));
            let wifibmp2 = Bmp::from_slice(include_bytes!("./img/wifi-2.bmp")).unwrap();
            let wifi_img2: Image<Bmp<BinaryColor>> = Image::new(&wifibmp2, Point::new(108,20));
            let wifibmp3 = Bmp::from_slice(include_bytes!("./img/wifi-3.bmp")).unwrap();
            let wifi_img3: Image<Bmp<BinaryColor>> = Image::new(&wifibmp3, Point::new(108,20));
            let wifibmp4 = Bmp::from_slice(include_bytes!("./img/wifi-4.bmp")).unwrap();
            let wifi_img4: Image<Bmp<BinaryColor>> = Image::new(&wifibmp4, Point::new(108,20));

            // PC sleep BMP
            let pcsleepbmp1 = Bmp::from_slice(include_bytes!("./img/pcsleep1.bmp")).unwrap();
            let pcsleep_img1: Image<Bmp<BinaryColor>> = Image::new(&pcsleepbmp1, Point::new(0,0));
            let pcsleepbmp2 = Bmp::from_slice(include_bytes!("./img/pcsleep2.bmp")).unwrap();
            let pcsleep_img2: Image<Bmp<BinaryColor>> = Image::new(&pcsleepbmp2, Point::new(0,0));
            let wakeuppcbmp = Bmp::from_slice(include_bytes!("./img/wakeup.bmp")).unwrap();
            let wakeuppc_img: Image<Bmp<BinaryColor>> = Image::new(&wakeuppcbmp, Point::new(0,0));
            // Push button BMP
            let pushbmp = Bmp::from_slice(include_bytes!("./img/pushbutton.bmp")).unwrap();
            let push_img: Image<Bmp<BinaryColor>> = Image::new(&pushbmp, Point::new(24,15));

            // Battery BMP
            let bat_x = 112;
            let bat_y = 42;
            let bat0 = Bmp::from_slice(include_bytes!("./img/battery-0.bmp")).unwrap();
            let bat0_img: Image<Bmp<BinaryColor>> = Image::new(&bat0, Point::new(bat_x, bat_y));
            let bat20 = Bmp::from_slice(include_bytes!("./img/battery-20.bmp")).unwrap();
            let bat20_img: Image<Bmp<BinaryColor>> = Image::new(&bat20, Point::new(bat_x, bat_y));
            let bat40 = Bmp::from_slice(include_bytes!("./img/battery-40.bmp")).unwrap();
            let bat40_img: Image<Bmp<BinaryColor>> = Image::new(&bat40, Point::new(bat_x, bat_y));
            let bat60 = Bmp::from_slice(include_bytes!("./img/battery-60.bmp")).unwrap();
            let bat60_img: Image<Bmp<BinaryColor>> = Image::new(&bat60, Point::new(bat_x, bat_y));
            let bat80 = Bmp::from_slice(include_bytes!("./img/battery-80.bmp")).unwrap();
            let bat80_img: Image<Bmp<BinaryColor>> = Image::new(&bat80, Point::new(bat_x, bat_y));
            let bat100 = Bmp::from_slice(include_bytes!("./img/battery-100.bmp")).unwrap();
            let bat100_img: Image<Bmp<BinaryColor>> = Image::new(&bat100, Point::new(bat_x, bat_y));
            let usbpwr = Bmp::from_slice(include_bytes!("./img/usb-power.bmp")).unwrap();
            let usbpwr_img: Image<Bmp<BinaryColor>> = Image::new(&usbpwr, Point::new(bat_x, bat_y));
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

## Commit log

2024-01-29 Add hardware data
    [bom.csv, bottom-v8.stl, button-center-v8.stl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]
2024-02-02 Fixed typo
    [bom.csv]
2026-02-14 Update for esp-idf-v5.4.2
    [partitions.csv]
2026-06-20 v0.2.0: Add WPS PBC support, fix display overlap and menu update
    - Add WPS PBC (Push Button Configuration) mode
    - Enabled via wps_enable=true in cfg.toml with empty wifi_ssid
    - Waits up to 120s for router WPS button press
    - Saves obtained SSID/PSK to NVS; disables WPS for subsequent boots
    - Fix WPS waiting display overlap
    - Remove \n from set_status messages in wifi.rs
    - Multi-line strings caused 2nd line (y=40) to overlap with
    second_msg rendered at same y coordinate (FONT_6X10 line height=10)
    - Fix WiFi menu not showing WPS credentials immediately after WPS
    - Add MenuTable::clear() to ui.rs
    - Call menu_table.clear() at start of initialize_menu() in displayctl.rs
    - Pre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
    [displayctl.rs, main.rs]

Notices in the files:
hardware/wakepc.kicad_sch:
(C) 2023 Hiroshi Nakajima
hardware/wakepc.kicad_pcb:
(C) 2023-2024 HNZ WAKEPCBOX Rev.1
